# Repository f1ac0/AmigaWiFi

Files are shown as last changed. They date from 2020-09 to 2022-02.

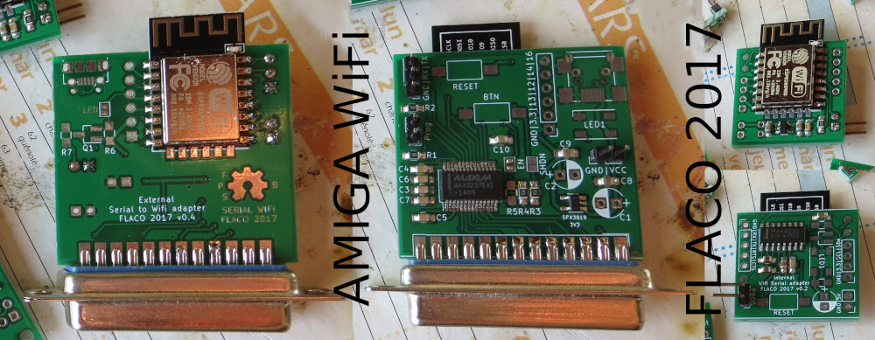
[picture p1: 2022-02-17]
AMIGA WiFi FLACO 2017.JPG

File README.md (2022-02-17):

# AmigaWiFi
Three different RS232 WiFi boards with ESP8266 to connect the Amiga to the world with Zimodem or esp\_slip\_router firmwares.

With Zimodem (https://github.com/bozimmerman/Zimodem) by Bo Zimmerman, this board can connect to telnet/BBS/xyzmodem/kermit services over IP on your local network or Internet.

With esp\_slip\_router (https://github.com/martin-ger/esp\_slip\_router) by Martin Ger, this board is a SLIP router to connect your Amiga to Internet.

The boards :
- AmigaWiFi3232_external : plugs into the DB25 serial port. Provides TX/RX/RTS/CTS for communication and hardware flow control. Needs external 5V supply through micro or mini-USB.
- AmigaWiFi3232_internal : connects internally. Provides TX/RX/RTS/CTS for communication and hardware flow control.
- AmigaWifi3237 : plugs into the DB25 serial port. Provides TX/RX/RTS/CTS/DTR/DSR/DCD/RI for communication, hardware flow control, carrier detect, ring. Needs external 5V supply through micro or mini-USB. Also has LED and display header that are not implemented at the moment.

Please note that the serial port on Amiga suffers some limitations. It is dependent on CPU speed : do not expect stable transfer at more than 33600 bauds with a 7MHz 68000, even with new8n1/baudbandit serial drivers. It is also dependent on screen bitplanes so you may need to set a 4 or even 2 colours mode before transfer.

# Disclaimer
This is a hobbyist project, it comes with no warranty and no support. Also remember that the Amiga machines are about 30 years old and may fail because of such hardware expansions.

This board is not connected to the firmware authors, please don't bother them with issues you might have because of it.

I publish this work using the CC-BY-NC-SA license.

If you find it useful and want to reward me : I am always looking for Amiga/Amstrad CPC hardware to repair and hack, please contact me.

# Making it
Some components are SMD. You need to know what you are doing.

Check for shorts at least between 5V, 3.3V, and GND traces before applying power !

The programming port does not need to be soldered since it needs to be programmed just once : you can just hold it in place during the few seconds required for programming.

The ESP8266 has to be programmed with a firmware. 3232 boards need to be programmed through a RS232 serial port on your PC so you need to physically connect it to the DB9 plug (commercial or homemade adapter). 3237 board can be programmed through its RS232 DB25 or through a TTL header depending on how you build it : check the schematic. In all cases you need to connect TX of the PC to RX of the board and vice-versa.

If you use the internal version of the board, disconnect any external device from the serial port. They cannot be used at the same time.

# Using it with Zimodem
Check the Zimodem project page on how to build it with the Arduino framework.

It is required to set the pinouts before building :
```
# define DEFAULT_PIN_DSR 5  //To computer DSR
# define DEFAULT_PIN_DTR 4  //To computer DTR
# define DEFAULT_PIN_RI 2 //To computer RI
# define DEFAULT_PIN_RTS 15 //To computer CTS (warning switched)
# define DEFAULT_PIN_CTS 13 //To computer RTS (warning switched)
# define PIN_EN 12
# define PIN_SHDN 14
```

In addition for 3237 version, enable the serial converter at beginning of setup :
```
void setup()
{
#ifdef PIN_EN //Enable 3237
  pinMode(PIN_EN, OUTPUT);
  digitalWrite(PIN_EN, LOW);
#endif
#ifdef PIN_SHDN //unSHDN 3237
  pinMode(PIN_SHDN, OUTPUT);
  digitalWrite(PIN_SHDN, HIGH);
#endif
```

Setup on the Amiga :
- install some terminal software like Term_4.8
- Setup serial device with appropriate baud rate, high speed mode (8N1), appropriate flow control, NO XON/XOFF. Disable local Echo.
- Setup transfer directories, then activate zmodem auto download
- Setup Zimodem:
```
ATI
ATB38400
ATW
ATW"ssid,pwd"
AT&W
```

To connect to a telnet/bbs service :
```
ATDT"towel.blinkenlights.nl:23"
```

To transfer a file from a PC on the LAN using sz :
- On the PC : `sz -b --tcp-server Files/to/transfer Another/file/to/transfer`
- Then on the Amiga connect to your PC IP and port given by sz : `ATD"192.168.1.2:32999"`
Transfer the file to the PC :
- On the Amiga : `ATA1234`
- On the PC : `sz -b --tcp-client 192.168.1.5`

If there are too many errors and retries :
- Lower the number of colours of the terminal app or Workbench.
- Increase buffers on Amiga.
- Activate hardware flow control both on Zimodem `ATF0` and Amiga (not sure if this is meaningful though). Use `ATF4` to disable it.
- Lower bitrate both on Zimodem `ATB19200` and Amiga (not too much otherwise sz will timeout during transfer).

# Using it with esp_slip_router
Check the esp\_slip\_router page on how to build the firmware.

By default the project does not use hardware flow control. You can choose to activate it before building, which will let you use the baudbandit serial driver on the Amiga. However beware that slattach during the PC test and setup procedure will not work anymore. To enable it, make these changes in include/driver/uart.h :
```
UART_HW_RTS 1
UART_HW_CTS 1
```

To setup the Amiga side I followed the guide : https://blog.nootch.net/post/amiga-bbs-online-2019/. With few additions : enable the "ignore DSR" feature, disable "Carrier detect" and use the "New8N1" serial driver. It works on my A600 with 68020 but Genesis does not work on my A500 with 68010 (not only the license file but also starting the app).

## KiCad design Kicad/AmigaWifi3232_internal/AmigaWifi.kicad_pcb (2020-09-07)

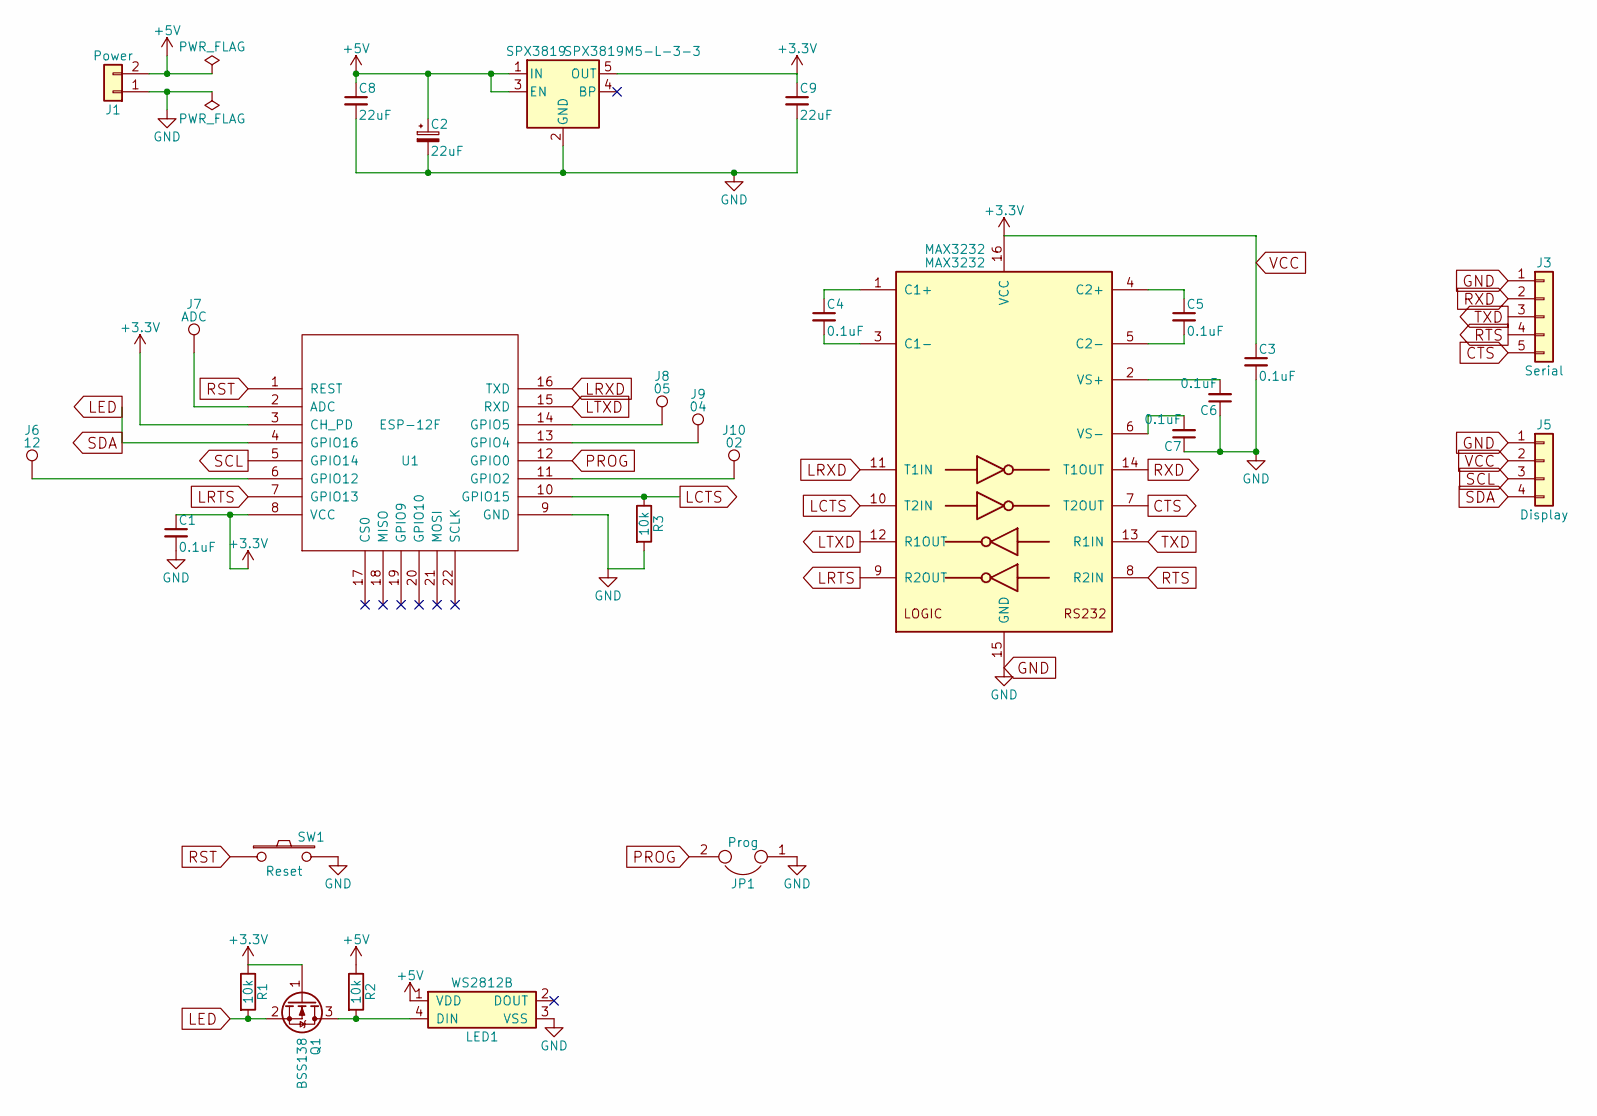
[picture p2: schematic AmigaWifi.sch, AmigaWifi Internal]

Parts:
C1, C3, C4, C5, C6, C7: 0.1uF; C_0805_HandSoldering
C2: 22uF; CP_Radial_D5.0mm_P2.50mm
C8, C9: 22uF; C_0805_HandSoldering
J1: Power; Pin_Header_Straight_1x02_Pitch2.54mm
J3: Serial; Pin_Header_Straight_1x05_Pitch2.54mm
J5: Display; Pin_Header_Straight_1x04_Pitch2.54mm
J6: 12; Measurement_Point_Round-SMD-Pad_Small
J7: ADC; Measurement_Point_Round-SMD-Pad_Small
J8: 05; Measurement_Point_Round-SMD-Pad_Small
J9: 04; Measurement_Point_Round-SMD-Pad_Small
J10: 02; Measurement_Point_Round-SMD-Pad_Small
JP1: Prog; Pin_Header_Straight_1x02_Pitch2.54mm
LED1: WS2812B; LED_WS2812B-PLCC4
MAX3232: MAX3232; SOIC-16_3.9x9.9mm_Pitch1.27mm
Q1: BSS138; SOT-23_Handsoldering
R1, R2, R3: 10k; R_0805_HandSoldering
SPX3819: SPX3819M5-L-3-3; SOT-23-5_HandSoldering
SW1: Reset; SW_SPST_FSMSM
U1: ESP-12F; ESP-12E_SMD

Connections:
+5V: C2.1, C8.1, J1.2, LED1.1 (VDD), R2.1, SPX3819.1 (IN), SPX3819.3 (EN)
CTS: J3.5, MAX3232.7 (T2OUT)
GND: C1.2, C2.2, C3.2, C6.1, C7.1, C8.2, C9.2, J1.1, J3.1, J5.1, JP1.1, LED1.3 (VSS), MAX3232.15 (GND), R3.2, SPX3819.2 (GND), SW1.2, U1.9 (GND)
LCTS: MAX3232.10 (T2IN), R3.1, U1.10 (GPIO15)
LED: J5.4, Q1.2 (S), R1.2, U1.4 (GPIO16)
LRTS: MAX3232.9 (R2OUT), U1.7 (GPIO13)
LRXD: MAX3232.11 (T1IN), U1.16 (TXD)
LTXD: MAX3232.12 (R1OUT), U1.15 (RXD)
unnamed: C4.1, MAX3232.1 (C1+)
unnamed: C4.2, MAX3232.3 (C1-)
unnamed: C5.1, MAX3232.4 (C2+)
unnamed: C5.2, MAX3232.5 (C2-)
unnamed: C6.2, MAX3232.2 (VS+)
unnamed: C7.2, MAX3232.6 (VS-)
unnamed: J6.1, U1.6 (GPIO12)
unnamed: J7.1, U1.2 (ADC)
unnamed: J8.1, U1.14 (GPIO5)
unnamed: J9.1, U1.13 (GPIO4)
unnamed: J10.1, U1.11 (GPIO2)
unnamed: LED1.4 (DIN), Q1.3 (D), R2.2
PROG: JP1.2, U1.12 (GPIO0)
RST: SW1.1, U1.1 (REST)
RTS: J3.4, MAX3232.8 (R2IN)
RXD: J3.2, MAX3232.14 (T1OUT)
SCL: J5.3, U1.5 (GPIO14)
TXD: J3.3, MAX3232.13 (R1IN)
VCC: C1.1, C3.1, C9.1, J5.2, MAX3232.16 (VCC), Q1.1 (G), R1.1, SPX3819.5 (OUT), U1.3 (CH_PD), U1.8 (VCC)

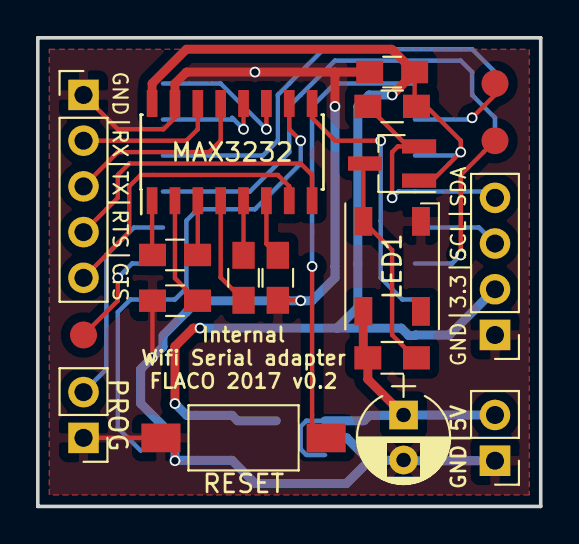
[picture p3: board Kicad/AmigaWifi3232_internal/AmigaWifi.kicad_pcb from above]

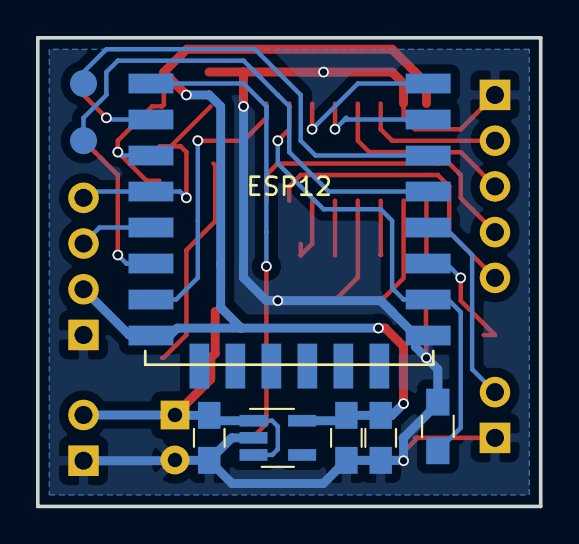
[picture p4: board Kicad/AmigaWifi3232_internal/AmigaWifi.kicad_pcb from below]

Board: 2 copper layers, 27.9 x 26.0 mm, 27 parts (8 on the bottom side), 27 nets.

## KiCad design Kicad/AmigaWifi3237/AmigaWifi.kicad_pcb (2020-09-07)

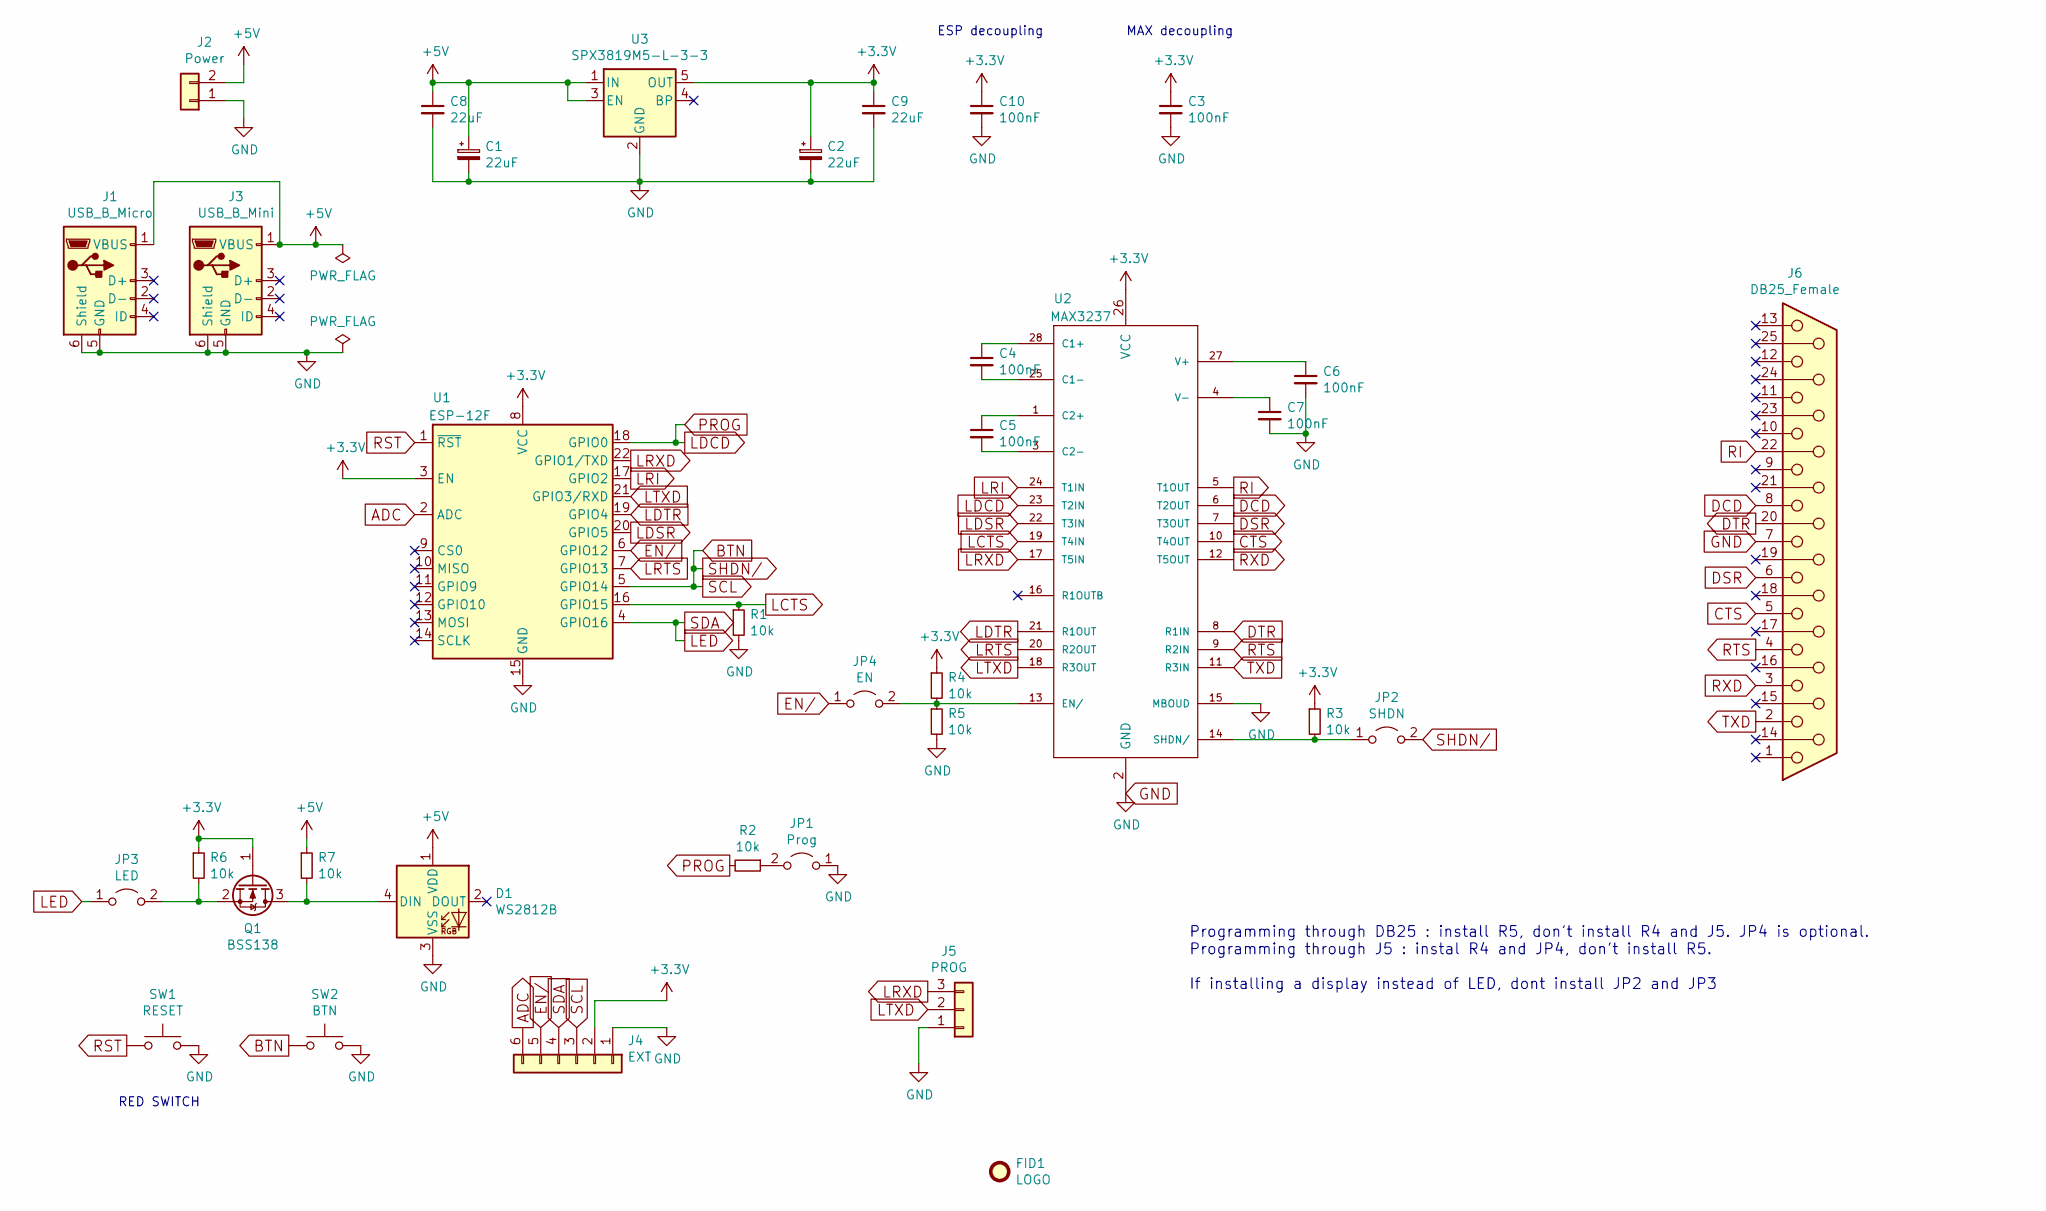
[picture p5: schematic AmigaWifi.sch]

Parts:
C1, C2: 22uF; CP_Radial_D5.0mm_P2.50mm
C3, C4, C5, C6, C7, C10: 100nF; C_0805_2012Metric_Pad1.15x1.40mm_HandSolder
C8, C9: 22uF; C_0805_2012Metric_Pad1.15x1.40mm_HandSolder
D1: WS2812B; LED_WS2812B_PLCC4_5.0x5.0mm_P3.2mm
FID1: LOGO; CC_BY_NC_SA_square_copper
J1: USB_B_Micro; USB_Micro-B_Molex-105017-0001
J2: Power; PinHeader_1x02_P2.54mm_Vertical
J3: USB_B_Mini; USB_Mini-B_Lumberg_2486_01_Horizontal
J4: EXT; PinHeader_1x06_P2.54mm_Vertical
J5: PROG; PinHeader_1x03_P2.54mm_Vertical
J6: DB25_Female; DSUB-25_Female_EdgeMount_P2.77mm
JP1: Prog; PinHeader_1x02_P2.54mm_Vertical
JP2: SHDN; SolderJumper-2_P1.3mm_Open_RoundedPad1.0x1.5mm
JP3: LED; SolderJumper-2_P1.3mm_Open_RoundedPad1.0x1.5mm
JP4: EN; SolderJumper-2_P1.3mm_Open_RoundedPad1.0x1.5mm
Q1: BSS138; SOT-23_Handsoldering
R1, R2, R3, R4, R5, R6, R7: 10k; R_0805_2012Metric_Pad1.15x1.40mm_HandSolder
SW1: RESET; SW_SPST_FSMSM
SW2: BTN; SW_SPST_FSMSM
U1: ESP-12F; ESP-12E
U2: MAX3237; SSOP-28_5.3x10.2mm_P0.65mm
U3: SPX3819M5-L-3-3; SOT-23-5_HandSoldering

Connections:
+3V3: C2.1, C3.1, C9.1, C10.1, J4.2, Q1.1 (G), R3.1, R4.1, R6.1, U1.3 (EN), U1.8 (VCC), U2.26 (VCC), U3.5 (OUT)
+5V: C1.1, C8.1, D1.1 (VDD), J1.1 (VBUS), J2.2, J3.1 (VBUS), R7.1, U3.1 (IN), U3.3 (EN)
ADC: J4.6, U1.2 (ADC)
BTN: J4.3, JP2.2 (B), SW2.1, U1.5 (GPIO14)
CTS: J6.5, U2.10 (T4OUT)
DCD: J6.8, U2.6 (T2OUT)
DSR: J6.6, U2.7 (T3OUT)
DTR: J6.20, U2.8 (R1IN)
EN/: J4.5, JP4.1 (A), U1.6 (GPIO12)
GND: C1.2, C2.2, C3.2, C6.2, C7.2, C8.2, C9.2, C10.2, D1.3 (VSS), J1.5 (GND), J1.6 (Shield), J2.1, J3.5 (GND), J3.6 (Shield), J4.1, J5.1, J6.7, JP1.1 (A), R1.2, R5.2, SW1.2, SW2.2, U1.15 (GND), U2.2 (GND), U2.15 (MBOUD), U3.2 (GND)
LCTS: R1.1, U1.16 (GPIO15), U2.19 (T4IN)
LDCD: R2.2, U1.18 (GPIO0), U2.23 (T2IN)
LDSR: U1.20 (GPIO5), U2.22 (T3IN)
LDTR: U1.19 (GPIO4), U2.21 (R1OUT)
LED: J4.4, JP3.1 (A), U1.4 (GPIO16)
LRI: U1.17 (GPIO2), U2.24 (T1IN)
LRTS: U1.7 (GPIO13), U2.20 (R2OUT)
LRXD: J5.3, U1.22 (GPIO1/TXD), U2.17 (T5IN)
LTXD: J5.2, U1.21 (GPIO3/RXD), U2.18 (R3OUT)
unnamed: C4.1, U2.28 (C1+)
unnamed: C4.2, U2.25 (C1-)
unnamed: C5.1, U2.1 (C2+)
unnamed: C5.2, U2.3 (C2-)
unnamed: C6.1, U2.27 (V+)
unnamed: C7.1, U2.4 (V-)
unnamed: D1.4 (DIN), Q1.3 (D), R7.2
unnamed: JP1.2 (B), R2.1
unnamed: JP2.1 (A), R3.2, U2.14 (SHDN/)
unnamed: JP3.2 (B), Q1.2 (S), R6.2
unnamed: JP4.2 (B), R4.2, R5.1, U2.13 (EN/)
RI: J6.22, U2.5 (T1OUT)
RST: SW1.1, U1.1 (~RST)
RTS: J6.4, U2.9 (R2IN)
RXD: J6.3, U2.12 (T5OUT)
TXD: J6.2, U2.11 (R3IN)

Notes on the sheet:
Programming through DB25 : install R5, don't install R4 and J5. JP4 is optional. Programming through J5 : instal R4 and JP4, don't install R5. If installing a display instead of LED, dont install JP2 and JP3
ESP decoupling
RED SWITCH
MAX decoupling

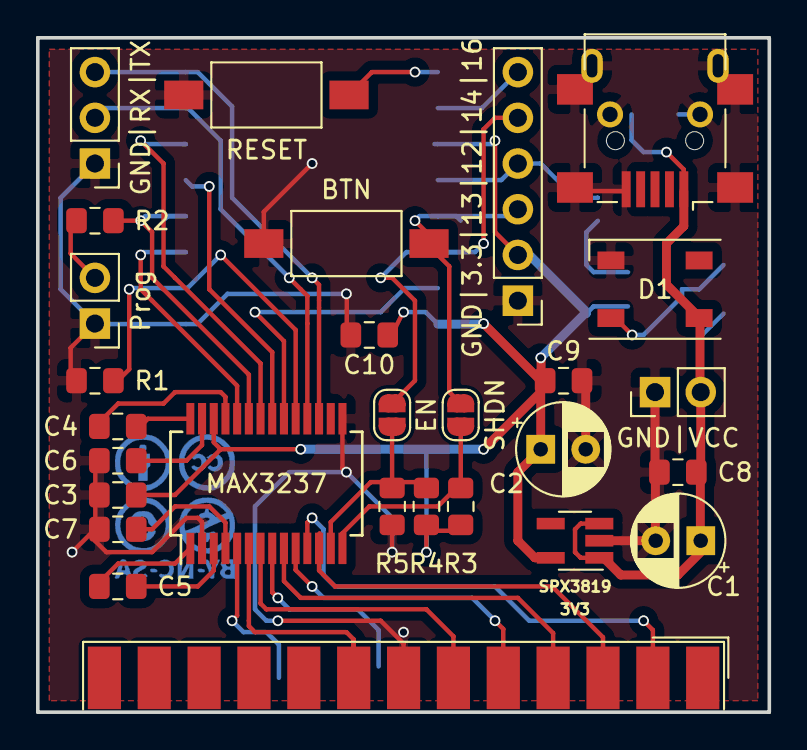
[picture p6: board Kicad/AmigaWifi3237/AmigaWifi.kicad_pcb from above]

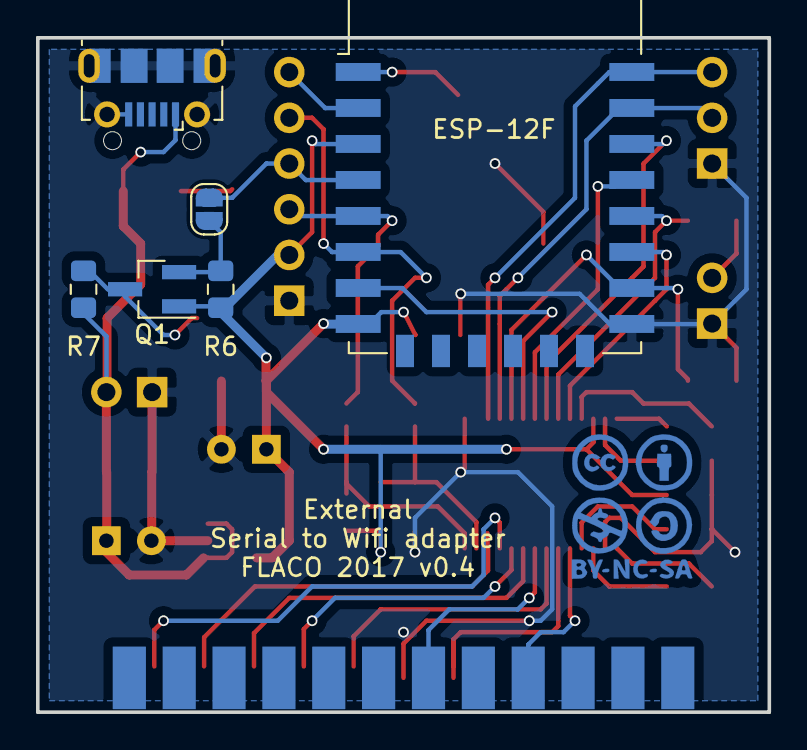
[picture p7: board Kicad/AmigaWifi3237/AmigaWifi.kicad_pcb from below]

Board: 2 copper layers, 40.6 x 37.5 mm, 35 parts (7 on the bottom side), 35 nets.

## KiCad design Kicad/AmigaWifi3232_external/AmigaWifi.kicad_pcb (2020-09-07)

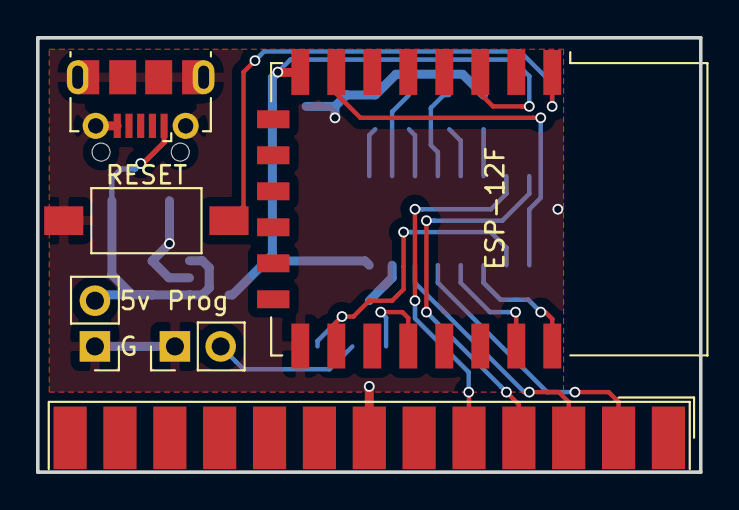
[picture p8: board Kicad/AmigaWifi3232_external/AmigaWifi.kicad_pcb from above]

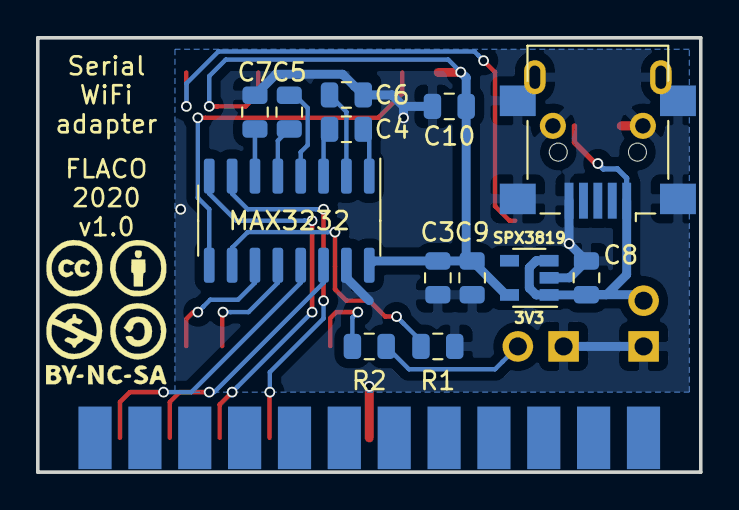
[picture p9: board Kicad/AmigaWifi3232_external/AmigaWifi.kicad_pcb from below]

Board: 2 copper layers, 36.8 x 24.1 mm, 20 parts (14 on the bottom side), 20 nets.

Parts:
C3, C4, C5, C6, C7, C10: 100nF; C_0805_2012Metric
C8, C9: 22uF; C_0805_2012Metric
FID1: LOGO; CC_BY_NC_SA_square_silkscreen
J1: USB_B_Micro; USB_Micro-B_Molex-105017-0001
J2: Power; PinHeader_1x02_P2.54mm_Vertical
J3: USB_B_Mini; USB_Mini-B_Lumberg_2486_01_Horizontal
J6: DB25_Female; DSUB-25_Female_EdgeMount_P2.77mm
JP1: Prog; PinHeader_1x02_P2.54mm_Vertical
R1, R2: 10k; R_0805_2012Metric
SW1: RESET; SW_SPST_FSMSM
U1: ESP-12F; ESP-12E
U2: MAX3232; SOIC-16_3.9x9.9mm_P1.27mm
U3: SPX3819M5-L-3-3; SOT-23-5

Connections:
+3V3: C3.1, C9.1, C10.1, U1.3, U1.8, U2.16, U3.5
+5V: C8.1, J1.1, J2.2, J3.1, U3.1, U3.3
CTS: J6.5, U2.7
GND: C3.2, C6.1, C7.1, C8.2, C9.2, C10.2, J1.5, J1.6, J2.1, J3.5, J3.6, J6.7, JP1.1, R1.2, SW1.2, U1.15, U2.15, U3.2
LCTS: R1.1, U1.16, U2.10
LRTS: U1.7, U2.9
LRXD: U1.22, U2.11
LTXD: U1.21, U2.12
unnamed: C4.1, U2.1
unnamed: C4.2, U2.3
unnamed: C5.1, U2.4
unnamed: C5.2, U2.5
unnamed: C6.2, U2.2
unnamed: C7.2, U2.6
unnamed: JP1.2, R2.1
PROG: R2.2, U1.18
RST: SW1.1, U1.1
RTS: J6.4, U2.8
RXD: J6.3, U2.14
TXD: J6.2, U2.13

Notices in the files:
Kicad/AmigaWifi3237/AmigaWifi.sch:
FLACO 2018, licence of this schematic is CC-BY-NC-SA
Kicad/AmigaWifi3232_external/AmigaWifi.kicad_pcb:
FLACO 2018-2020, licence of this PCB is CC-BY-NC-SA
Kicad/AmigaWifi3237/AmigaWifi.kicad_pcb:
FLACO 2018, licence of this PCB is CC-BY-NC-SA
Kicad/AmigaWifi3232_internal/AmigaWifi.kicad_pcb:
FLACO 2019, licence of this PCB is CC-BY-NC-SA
